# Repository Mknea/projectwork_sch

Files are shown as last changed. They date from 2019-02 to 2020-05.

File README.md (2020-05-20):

# Project work pcb design

This repository contains the KiCAD schematic and pcb layout files used in Project work course. The designed boards were used in conjunction with developed mobile app to automate a popular finnish outdoor game, Mölkky.

Both macro- and microboard-versions of the design were manufactured, components were soldered in, and the proper functioning of the whole product was both verified and demonstrated.

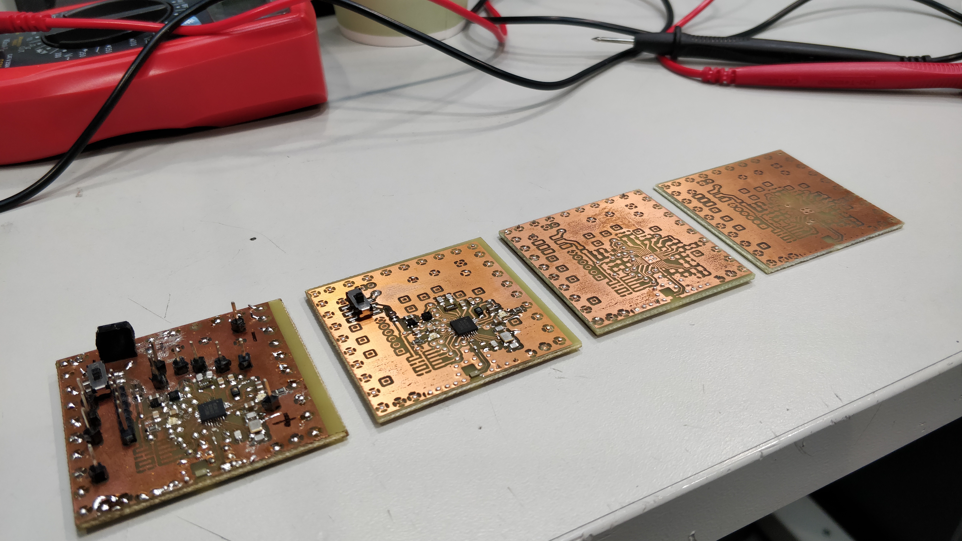
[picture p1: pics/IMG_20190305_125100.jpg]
Macroboard manufacturing stages

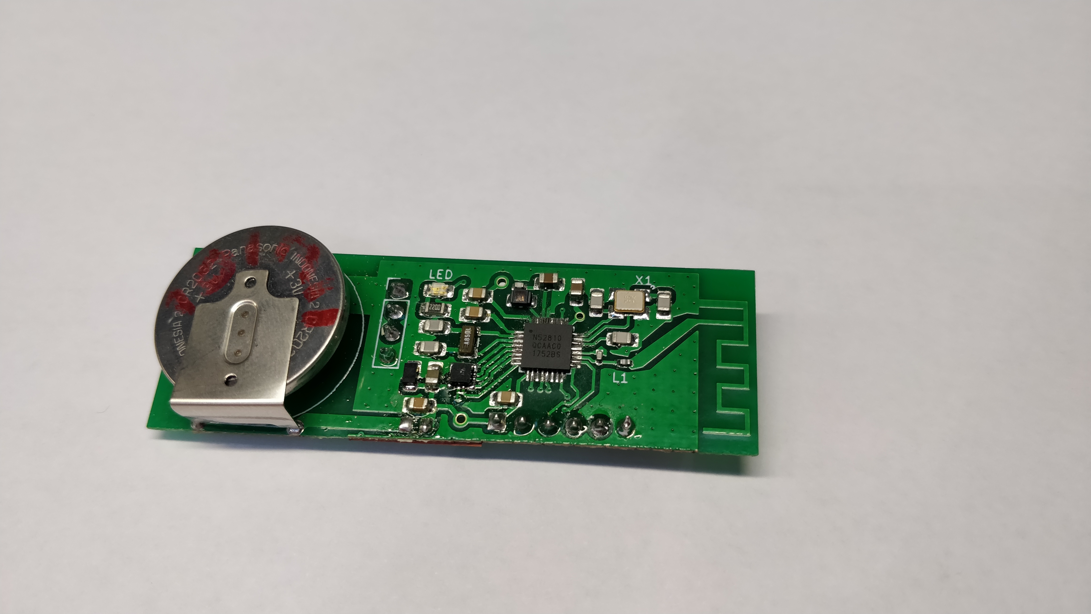
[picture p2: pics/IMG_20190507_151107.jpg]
Final microboard assembled

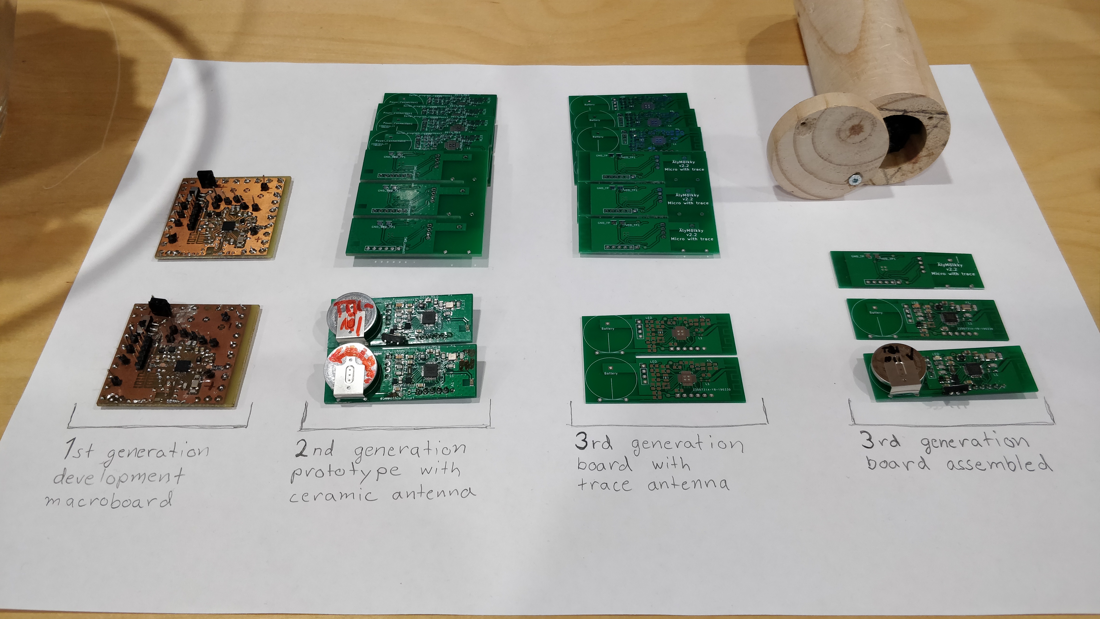
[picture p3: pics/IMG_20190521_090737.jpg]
All of the revisions All of the revisions on display

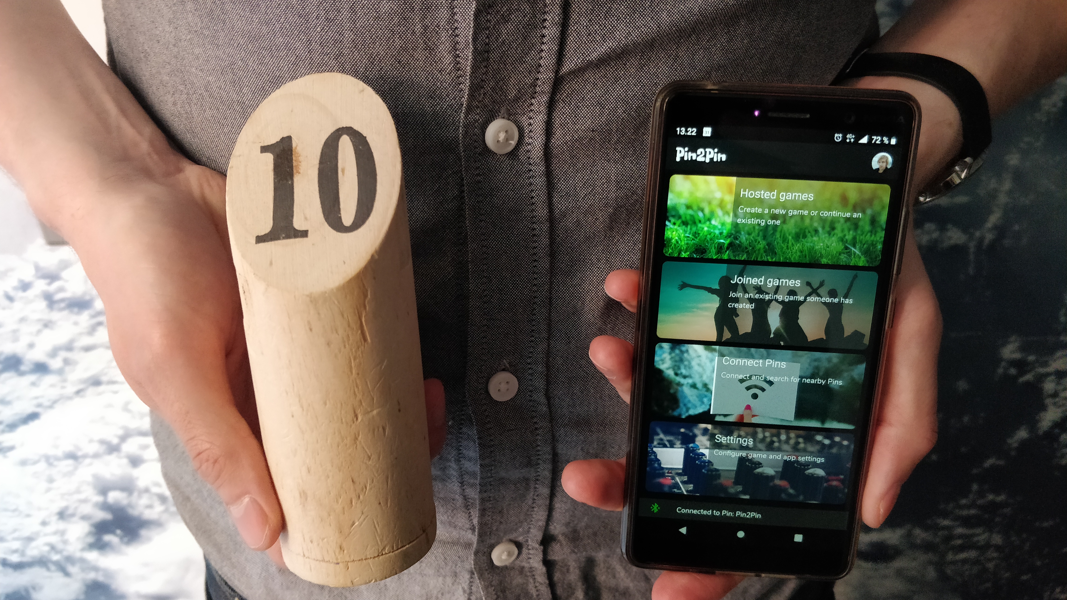
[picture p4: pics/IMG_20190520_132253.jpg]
Final product Final product, with board inside the game pin


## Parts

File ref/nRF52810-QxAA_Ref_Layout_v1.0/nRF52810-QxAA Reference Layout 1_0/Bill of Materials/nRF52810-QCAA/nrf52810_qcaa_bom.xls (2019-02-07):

Bill of material
Board: | nRF52810-QCAA Reference Layout
Version: | 1.0
Designator | Value | Description | Footprint Doc
C1, C2, C11, C12 | 12pF | Capacitor, NP0, ±2% | 0402
C3 | 0.8pF | Capacitor, NP0, ±5% | 0402
C4, C5, C8 | 100nF | Capacitor, X7R, ±10% | 0402
C6 | N.C. | Not mounted | 0402
C7 | 100pF | Capacitor, NP0, ±5% | 0402
C9 | 4.7µF | Capacitor, X5R, ±10% | 0603
C10 | 1.0µF | Capacitor, X7R, ±10% | 0603
L1 | 3.9nH | High frequency chip inductor ±5% | 0402
U1 | nRF52810-QCAA | Multi-protocol Bluetooth Low Energy, ANT and 2.4GHz proprietary system-on-chip | QFN-32
X1 | 32MHz | XTAL SMD 2016, 32MHz, Cl=8pF, Total Tol: ±40ppm | XTAL_2016
X2 | 32.768kHz | XTAL SMD 3215, 32.768kHz, Cl=9pF, Total Tol: ±50ppm | XTAL_3215

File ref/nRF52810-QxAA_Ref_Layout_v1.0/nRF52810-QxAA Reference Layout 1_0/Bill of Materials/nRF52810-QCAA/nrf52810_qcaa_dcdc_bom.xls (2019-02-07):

Bill of material
Board: | nRF52810-QCAA Reference Layout (DCDC)
Version: | 1.0
Designator | Value | Description | Footprint Doc
C1, C2, C11, C12 | 12pF | Capacitor, NP0, ±2% | 0402
C3 | 0.8pF | Capacitor, NP0, ±5% | 0402
C4, C5, C8 | 100nF | Capacitor, X7R, ±10% | 0402
C6, C13 | N.C. | Not mounted | 0402
C7 | 100pF | Capacitor, NP0, ±5% | 0402
C9 | 4.7µF | Capacitor, X5R, ±10% | 0603
C10 | 1.0µF | Capacitor, X7R, ±10% | 0603
L1 | 3.9nH | High frequency chip inductor ±5% | 0402
L2 | 10µH | Chip inductor, IDC,min = 50 mA, ±20% | 0603
L3 | 15nH | High frequency chip inductor ±10% | 0402
U1 | nRF52810-QCAA | Multi-protocol Bluetooth Low Energy, ANT and 2.4GHz proprietary system-on-chip | QFN-32
X1 | 32MHz | XTAL SMD 2016, 32MHz, Cl=8pF, Total Tol: ±40ppm | XTAL_2016
X2 | 32.768kHz | XTAL SMD 3215, 32.768kHz, Cl=9pF, Total Tol: ±50ppm | XTAL_3215

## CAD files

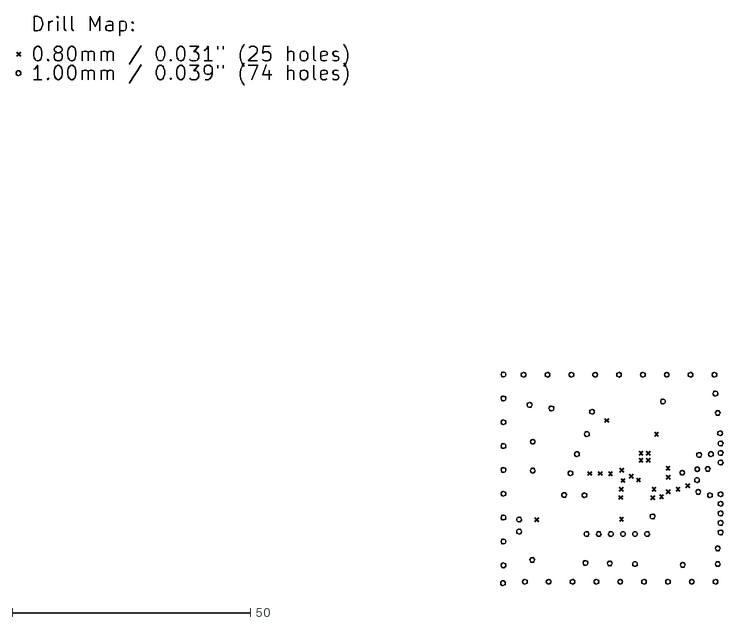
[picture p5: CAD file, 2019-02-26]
KiCAD microboard trace-antennalla filet/Älymölkky-PTH-drl_map.dxf
148.2 x 119.3

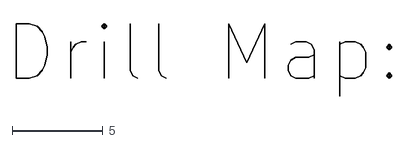
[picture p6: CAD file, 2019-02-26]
KiCAD microboard trace-antennalla filet/Älymölkky-NPTH-drl_map.dxf
20.7 x 4.00

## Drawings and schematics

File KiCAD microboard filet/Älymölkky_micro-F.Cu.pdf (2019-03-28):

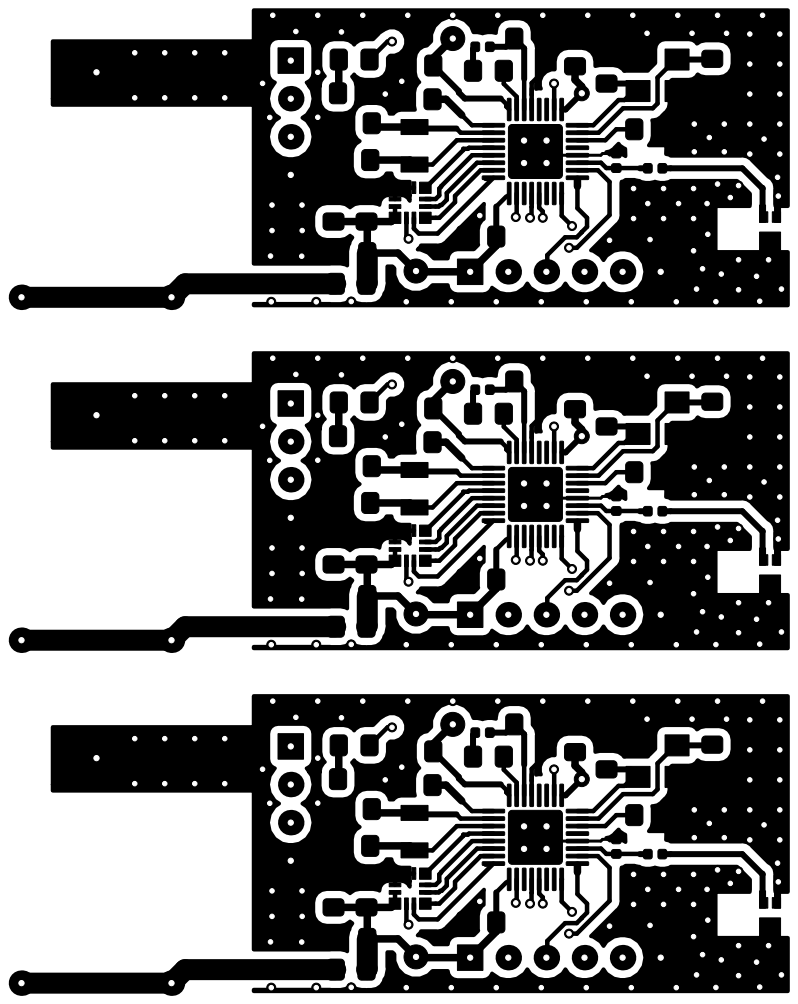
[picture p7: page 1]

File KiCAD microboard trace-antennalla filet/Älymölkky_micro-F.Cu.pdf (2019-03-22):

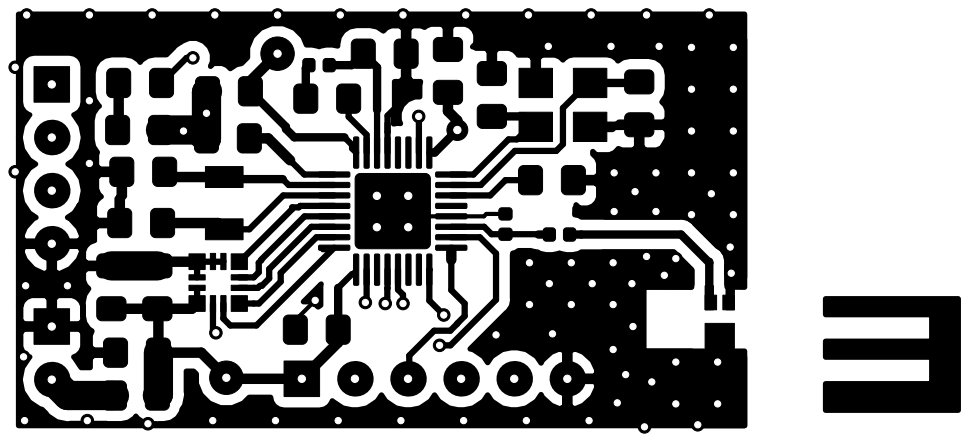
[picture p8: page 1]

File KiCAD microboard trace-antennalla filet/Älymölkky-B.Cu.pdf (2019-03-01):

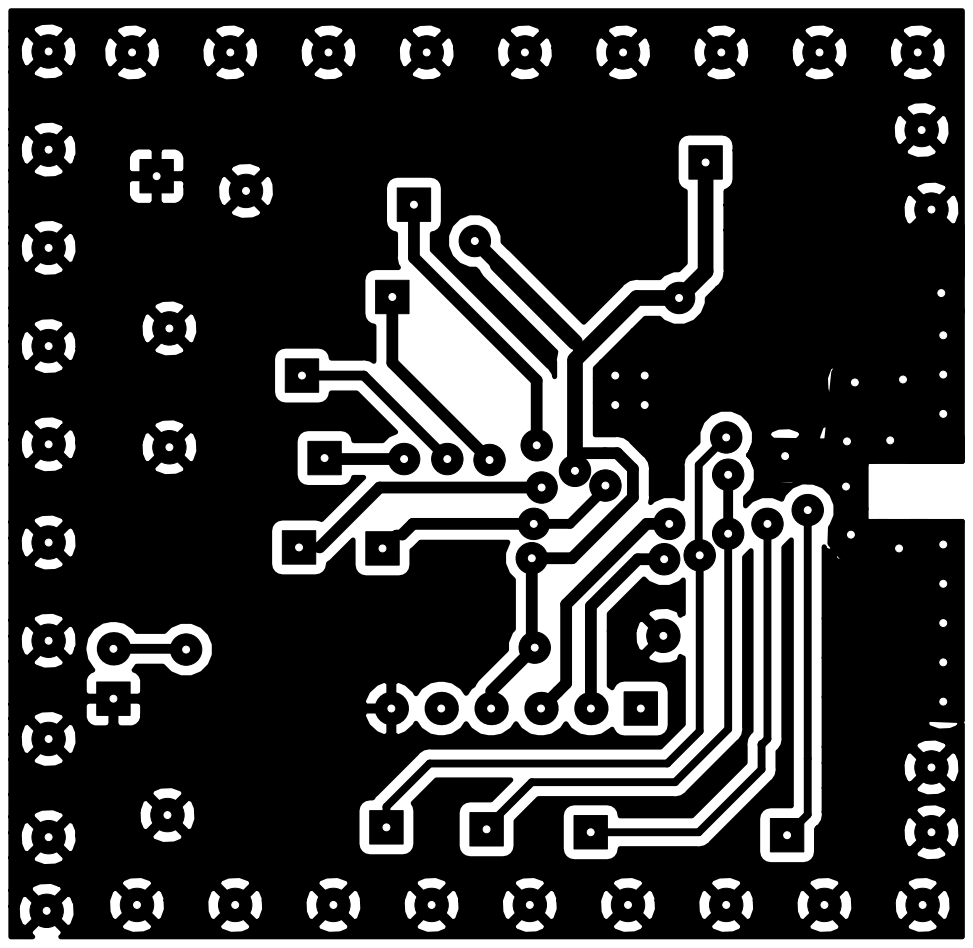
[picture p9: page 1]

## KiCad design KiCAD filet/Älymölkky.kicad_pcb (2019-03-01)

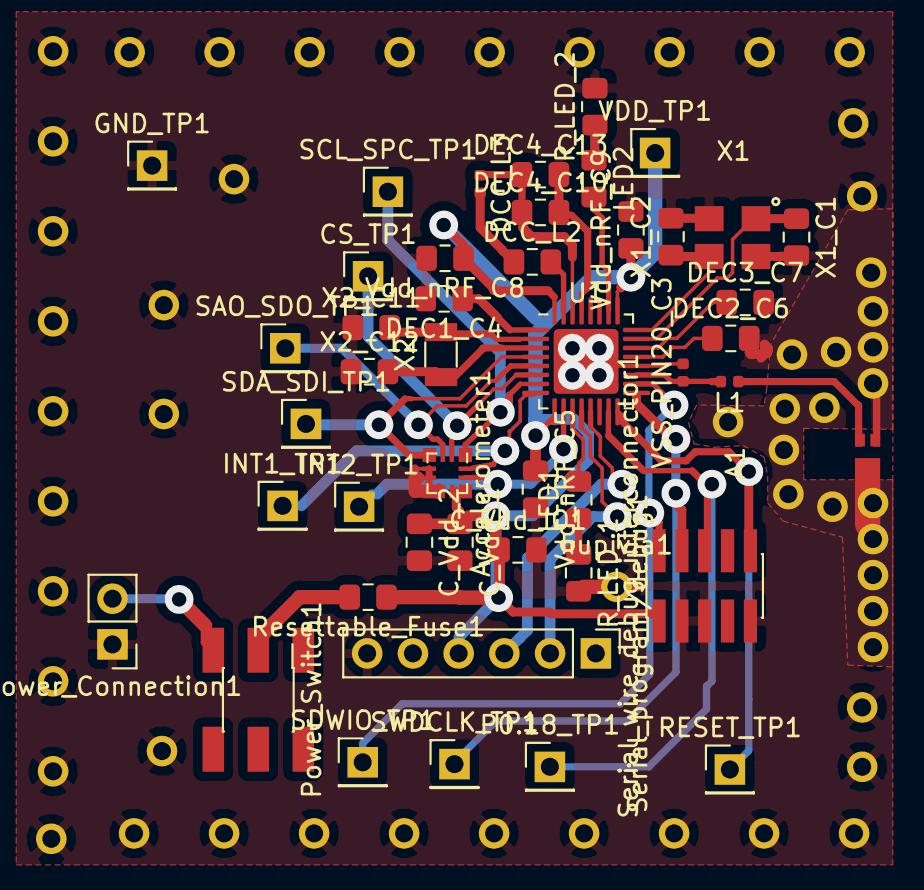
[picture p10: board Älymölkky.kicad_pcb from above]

Board: 2 copper layers, 46 parts (0 on the bottom side), 32 nets.

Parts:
A1: ACAG0201-2450-T
Accelerometer1: LIS2DE12; LGA-12_2x2mm_P0.5mm
CS_TP1: Conn_01x01_Male; PinHeader_1x01_P2.54mm_Vertical
C_Vdd_1: 100uF; C_0805_2012Metric_Pad1.15x1.40mm_HandSolder
C_Vdd_2: 10uF; C_0805_2012Metric_Pad1.15x1.40mm_HandSolder
C_Vdd_IO1: 100nF; C_0805_2012Metric_Pad1.15x1.40mm_HandSolder
DCC_L2: 10uH; C_0805_2012Metric_Pad1.15x1.40mm_HandSolder
DCC_L3: 15nH; C_0402_1005Metric
DEC1_C4: 100nF; C_0805_2012Metric_Pad1.15x1.40mm_HandSolder
DEC2_C6, DEC4_C13: N.C.; C_0805_2012Metric_Pad1.15x1.40mm_HandSolder
DEC3_C7: 100pF; C_0805_2012Metric_Pad1.15x1.40mm_HandSolder
DEC4_C10: 1.0uF; C_0805_2012Metric_Pad1.15x1.40mm_HandSolder
GND_TP1: Conn_01x01_Male; PinHeader_1x01_P2.54mm_Vertical
INT1_TP1, INT2_TP1: Conn_01x01_Male; PinHeader_1x01_P2.54mm_Vertical
L1: 3.9nH; R_0402_1005Metric
LED1, LED2: LED_ALT; R_0805_2012Metric_Pad1.15x1.40mm_HandSolder
P0.18_TP1: Conn_01x01_Male; PinHeader_1x01_P2.54mm_Vertical
Power_Connection1: Conn_01x02_Female; PinHeader_1x02_P2.54mm_Vertical
Power_Switch1: Conn_02x03_Odd_Even; PinHeader_2x03_P1.27mm_Vertical_SMD
RESET_TP1: Conn_01x01_Male; PinHeader_1x01_P2.54mm_Vertical
R_LED_1, R_LED_2: 220; R_0805_2012Metric_Pad1.15x1.40mm_HandSolder
Resettable_Fuse1: Polyfuse; R_0805_2012Metric_Pad1.15x1.40mm_HandSolder
SAO_SDO_TP1: Conn_01x01_Male; PinHeader_1x01_P2.54mm_Vertical
SCL_SPC_TP1: Conn_01x01_Male; PinHeader_1x01_P2.54mm_Vertical
SDA_SDI_TP1: Conn_01x01_Male; PinHeader_1x01_P2.54mm_Vertical
SDWIO_TP1: Conn_01x01_Male; PinHeader_1x01_P2.54mm_Vertical
SWDCLK_TP1: Conn_01x01_Male; PinHeader_1x01_P2.54mm_Vertical
Serial_program/debug1: Conn_01x06_Male; PinHeader_1x06_P2.54mm_Vertical
Serial_wire_debug_interconnector1: Conn_02x05_Odd_Even; PinHeader_2x05_P1.27mm_Vertical_SMD
U1: nRF52810-QCxx; QFN-32-1EP_5x5mm_P0.5mm_EP3.6x3.6mm
VDD_TP1: Conn_01x01_Male; PinHeader_1x01_P2.54mm_Vertical
VSS_PIN20_C3: 0.8pF; C_0402_1005Metric
Vdd_nRF_C5, Vdd_nRF_C8: 100nF; C_0805_2012Metric_Pad1.15x1.40mm_HandSolder
Vdd_nRF_C9: 4.7uF; C_0805_2012Metric_Pad1.15x1.40mm_HandSolder
X1: 32MHz Crystal; Crystal_3.2x2.5x0.8
X1_C1, X1_C2, X2_C11, X2_C12: 12pF; C_0805_2012Metric_Pad1.15x1.40mm_HandSolder
X2: 32.768 kHz Crystal; Crystal_SMD_3215-2Pin_3.2x1.5mm
hupivia1: Conn_01x01_Male; PinHeader_1x01_P2.54mm_Vertical

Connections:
/ANTENNA: A1.1, L1.1
/~CS: Accelerometer1.2, CS_TP1.1, U1.6
/~INT1: Accelerometer1.12, INT1_TP1.1, U1.8
/~INT2: Accelerometer1.11, INT2_TP1.1, U1.10
/~RX1: Serial_program/debug1.2, U1.12
/~Reset: RESET_TP1.1, Serial_wire_debug_interconnector1.10, U1.16
/~SAO_SDO: Accelerometer1.3, SAO_SDO_TP1.1, U1.5
/~SCL_SPC: Accelerometer1.1, SCL_SPC_TP1.1, U1.7
/~SDA_SDI: Accelerometer1.4, SDA_SDI_TP1.1, U1.4
/~SWDCLK: SWDCLK_TP1.1, Serial_wire_debug_interconnector1.4, U1.17
/~SWDIO: SDWIO_TP1.1, Serial_wire_debug_interconnector1.2, U1.18
/~SWO: P0.18_TP1.1, Serial_wire_debug_interconnector1.6, U1.15
/~TX0: Serial_program/debug1.3, U1.13
Earth: A1.2, A1.3, Accelerometer1.5, Accelerometer1.6, Accelerometer1.7, Accelerometer1.8, C_Vdd_1.2, C_Vdd_2.2, C_Vdd_IO1.2, DEC1_C4.2, DEC2_C6.2, DEC3_C7.2, DEC4_C10.2, DEC4_C13.2, GND_TP1.1, Power_Connection1.1, R_LED_1.2, R_LED_2.2, Serial_program/debug1.6, Serial_wire_debug_interconnector1.3, Serial_wire_debug_interconnector1.5, Serial_wire_debug_interconnector1.9, U1.20, U1.29, U1.33, VSS_PIN20_C3.2, Vdd_nRF_C5.2, Vdd_nRF_C8.2, Vdd_nRF_C9.2, X1.2, X1.4, X1_C1.2, X1_C2.2, X2_C11.1, X2_C12.1, hupivia1.1
unnamed: DCC_L2.1, DCC_L3.2
unnamed: DCC_L2.2, U1.31
unnamed: DCC_L3.1, DEC4_C10.1, DEC4_C13.1, U1.30
unnamed: DEC1_C4.1, U1.1
unnamed: DEC2_C6.1, U1.21
unnamed: DEC3_C7.1, U1.22
unnamed: L1.2, U1.19, VSS_PIN20_C3.1
unnamed: LED1.1, R_LED_1.1
unnamed: LED1.2, U1.11
unnamed: LED2.1, R_LED_2.1
unnamed: LED2.2, U1.26
unnamed: Power_Connection1.2, Power_Switch1.5
unnamed: Power_Switch1.3, Resettable_Fuse1.2
unnamed: U1.2, X2.1, X2_C11.2
unnamed: U1.3, X2.2, X2_C12.2
unnamed: U1.23, X1.1, X1_C1.1
unnamed: U1.24, X1.3, X1_C2.1
VDD: Accelerometer1.9, Accelerometer1.10, C_Vdd_1.1, C_Vdd_2.1, C_Vdd_IO1.1, Resettable_Fuse1.1, Serial_program/debug1.4, Serial_wire_debug_interconnector1.1, U1.9, U1.25, U1.32, VDD_TP1.1, Vdd_nRF_C5.1, Vdd_nRF_C8.1, Vdd_nRF_C9.1

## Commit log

2019-02-06 Datasheetit pääkomponenteista ja ref. schematic microcontrollerille
2019-02-06 Added file placeholder into new folder KiCAD filet
2019-02-06 Initial schematic
    [Älymölkky.kicad_pcb, Älymölkky.sch]
2019-02-07 Added lots of new reference files and a new lib
    [nrf52810_qcaa.DRL, nrf52810_qcaa.GBL, nrf52810_qcaa.GBO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]
2019-02-07 Removed redundant files and more cleanup
    [Älymölkky.sch]
2019-02-07 Added separate schematic for breakout board (done using nRF52832, not 10!)
    [ÄlyMölkky_breakout.kicad_pcb, ÄlyMölkky_breakout.sch]
2019-02-07 Breakout and dev schematics added.
2019-02-11 Added most of nrf52 pin connections
    [Älymölkky.sch]
2019-02-11 Added comments on some pins
    [Älymölkky.sch]
2019-02-12 Added test points, leds and serial port programming pins
    [Älymölkky.sch]
2019-02-12 Added PCB component layouts
    [Älymölkky.sch]
2019-02-14 Changed the circuit to allow internal DC/DC converter to be used
    [Älymölkky.sch]
2019-02-14 Added pcb layouts for components and initialized the layout work
    [Älymölkky.sch]
2019-02-18 Added fuse, modified nRF and LIS footprints and started layout work
    [Älymölkky.kicad_pcb, Älymölkky.sch]
2019-02-22 Added more traces, shifted one pin's place and will shift more soon
    [Älymölkky.kicad_pcb, Älymölkky.sch]
2019-02-22 Reorganized more pins, drew LIS traces
    [Älymölkky.kicad_pcb, Älymölkky.sch]
2019-02-25 Drew most of remaining traces, missing antenna and switch
    [Älymölkky.kicad_pcb]
2019-02-26 Added changes made by Pyry, antenna, copper pour and slight changes
    [Älymölkky.kicad_pcb, Älymölkky.sch]
2019-02-26 Added switch, modified components to right sizes
    [Älymölkky.kicad_pcb, Älymölkky.sch]
2019-02-26 Preparations for drilling
    [noname.kicad_pcb, Älymölkky-NPTH-drl_map.dxf, Älymölkky-PTH-drl_map.dxf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]
2019-03-01 Modified some traces, larger size capacitors on crystal
    [Älymölkky.kicad_pcb]
2019-03-12 Added microboard as separate folder with separate designs
    [noname.kicad_pcb, ÄlyMölkky_breakout.kicad_pcb, ÄlyMölkky_breakout.sch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]
2019-03-12 Changed programming interface to standalone pinheaders
    [Älymölkky_micro.kicad_pcb, Älymölkky_micro.sch]
2019-03-15 Re-arranged most of the layout to more compact form, missing antennas
    [Älymölkky_micro.kicad_pcb]
2019-03-18 Changed serial programming pin locations and order, reorganized whole board
    [Älymölkky_micro.kicad_pcb, Älymölkky_micro.sch]
2019-03-22 Changed all vias to smaller size, passed electronic rule check
    [Älymölkky_micro.kicad_pcb]
2019-03-26 Added battery vias and drew preliminary trace antenna
    [_saved_Älymölkky_micro.sch, Älymölkky_micro.kicad_pcb]
2019-03-26 Added new file for order with trace antenna, multiplied the ceramic antenna order pcb for order
    [_saved_Älymölkky_micro.sch, ÄlyMölkky_breakout.kicad_pcb, ÄlyMölkky_breakout.sch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]
2019-03-28 Staging to build traceantenna
    [noname.kicad_pcb, Älymölkky_micro_traceantenna.sch]
2019-03-28 Readymade design with antenna, only antenna connection not wide enough, needs 3mm
    [Älymölkky_micro_traceantenna.kicad_pcb]
2019-03-28 Trace antenna design completed, modifying for order
    [Älymölkky_micro_traceantenna.kicad_pcb]
2019-03-28 Order ready trace antenna design
    [Älymölkky_micro_traceantenna.kicad_pcb]
